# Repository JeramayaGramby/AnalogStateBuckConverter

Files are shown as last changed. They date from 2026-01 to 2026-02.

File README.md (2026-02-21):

# Multi-Range Analog State Buck Converter

A deliberately over-engineered, pedagogically motivated power-electronics platform that demonstrates how classical analog circuitry can implement deterministic state behavior — without a microcontroller, firmware, or digital logic.

---

## Table of Contents

- [Multi-Range Analog State Buck Converter](#multi-range-analog-state-buck-converter)
  - [Table of Contents](#table-of-contents)
  - [Overview](#overview)
  - [Functional Description](#functional-description)
    - [State Table](#state-table)
    - [Enable Logic](#enable-logic)
  - [Design Philosophy \& Constraints](#design-philosophy--constraints)
    - [1. All Components Must Be Sourced From American Manufacturers](#1-all-components-must-be-sourced-from-american-manufacturers)
    - [2. Every Component Must Have a Complete Digital Asset Package](#2-every-component-must-have-a-complete-digital-asset-package)
    - [3. No Obsolete, End-of-Life, or Newly Released Components](#3-no-obsolete-end-of-life-or-newly-released-components)
  - [Use Case \& Motivation](#use-case--motivation)
  - [Challenges](#challenges)
  - [Potential Improvements](#potential-improvements)
  - [Repository Structure](#repository-structure)
  - [Educational \& Professional Value](#educational--professional-value)

---

## Overview

The **Multi-Range Analog State Machine Buck Converter** accepts a wide, potentially unstable input voltage (5 V – 24 V) and autonomously selects one of three independent buck converter stages based on the instantaneous input voltage. Each stage is optimized for a specific voltage window, ensuring predictable, safe, and efficient **5 V regulation** even in environments where electrical infrastructure is unreliable or inconsistent.

At its core, the system is an **analog state machine** built from comparators, open-collector logic, a dual NPN transistor, and a P-channel MOSFET high-side switch. State transitions are governed entirely by analog voltage thresholds and hysteresis — no firmware, no lookup tables, no digital logic.

| Parameter | Value |
|---|---|
| Input Voltage Range | 5 V – 24 V |
| Output Voltage | 5 V (regulated) |
| Recommended Output Current | 2 A |
| Absolute Max Output Current | 3 A |
| Active Buck Stages | 3 (mutually exclusive) |
| Control Architecture | Analog state machine |

---

## Functional Description

The system operates in four mutually exclusive states, each defined by the instantaneous input voltage $V_{IN}$.

### State Table

| $V_{IN}$ Range | Active State | Behavior |
|---|---|---|
| < 5 V | State 0 | System disabled; no buck converter enabled |
| 5 V – 9.25 V | State 1 | Buck 1 enabled |
| 9.25 V – 12.25 V | State 2 | Buck 2 enabled |
| > 12.25 V | State 3 | Buck 3 enabled |

### Enable Logic

Three comparators generate threshold signals $F_1$, $F_2$, $F_3$, which are combined into per-stage enable signals:

$$EN_1 = F_1 \cdot \overline{F_2}$$

$$EN_2 = F_2 \cdot \overline{F_3}$$

$$EN_3 = F_3$$

This guarantees that **only one buck converter can ever be active at a time**, eliminating overlap, shoot-through, and undefined states. The Boolean logic is implemented using open-collector outputs and a dual NPN transistor pair — producing clean, debuggable, and observable behavior without relying on any digital ICs.

---

## Design Philosophy & Constraints

This project was built under a strict set of real-world constraints to simulate the pressures of professional hardware development and supply-chain engineering.

### 1. All Components Must Be Sourced From American Manufacturers

In response to the tariff volatility and supply-chain instability of 2025, every component — down to each resistor and capacitor — must be manufactured in the United States. This constraint forces:

- Working within a limited vendor ecosystem
- Understanding the geopolitical and regulatory implications of component sourcing
- Building a design resilient to international supply disruptions

It also ensures that all components share the same manufacturing standards, tolerances, and compliance frameworks.

### 2. Every Component Must Have a Complete Digital Asset Package

To eliminate common PCB design bottlenecks, every part must include:

- A verified schematic symbol
- A verified PCB footprint
- A manufacturer-provided 3D model
- A complete datasheet

This rule was established after the very first component selected for the project had no symbol, no footprint, and no 3D model. After wrestling with mismatched footprints and incomplete documentation, the policy became absolute: **no part enters the design unless it is fully documented and fully modeled.**

This dramatically reduces layout errors, accelerates ECO cycles, and ensures the final 3D assembly is accurate enough for enclosure design, thermal modeling, and manufacturing review.

### 3. No Obsolete, End-of-Life, or Newly Released Components

Only parts with:

- At least **1,000 units in stock** at the time of selection
- **Stable production status**
- **Mature documentation**

This avoids designing around parts that may disappear, change spec, or lack real-world validation.

---

## Use Case & Motivation

The device is designed for environments where electrical infrastructure is **inconsistent, under-regulated, or prone to voltage fluctuations** — conditions common in many developing regions. While handheld device chargers in first-world countries typically include robust overvoltage and overcurrent protection, this is not universally true.

By supporting a 5–24 V input range and regulating to a stable 5 V output, the system provides a safe, predictable power source for:

- Mobile devices
- Portable electronics
- Embedded systems
- Field equipment

The analog state machine ensures the correct buck converter is always selected for the input voltage, protecting downstream devices from unstable or dangerous power conditions.

---

## Challenges

> As this is one of my first PCB designs, there were no shortages of challenges.
> The first lesson I learned in PCB design pertaining to the numerous revisions is that every year, at the end of January, automotive manufacturers will order any and every automotive rated peripheral, whether it is AEC-5000 rated, AEC-1200 rated, or barely CE certified.
> Around 41% of this PCB's components are Automotive rated, and this means that the Bill of Materials needed several revisions to ensure the design continued to meet sourceability constraints. Irreplaceable components are noted in the Bill of Materials along with potential drop in replacements. 
> There are several components that currently do not meet the sourcability requirements, even before the end of January. This includes the final diode, the NPN transistor and the P channel MOSFET. The voltage requirements for these components limit the number of drop-in replacement options.   
---

## Potential Improvements

> *This section is reserved for proposed enhancements, alternative architectures, and future revision ideas.*

---

## Repository Structure

```
AnalogStateBuckConverter/
├── altium_footprints/      # Altium schematic symbols and PCB footprints (by block)
├── cad/
│   ├── project_files/      # KiCad schematic and PCB project files
│   └── step/               # 3D STEP models (by block)
├── docs/
│   ├── BOM/                # Bill of materials
│   ├── datasheets/         # Component datasheets (by block)
│   ├── symbols/            # Schematic symbol assets (by block)
│   └── History/            # Design revision history
└── footprints/             # KiCad footprint files (by block)
```

---

## Educational & Professional Value

This project is intentionally over-engineered — and that is its strength. It serves as a comprehensive learning platform merging:

| Domain | Topics Covered |
|---|---|
| Analog Circuit Design | Comparators, hysteresis, open-collector logic, MOSFET switching |
| Power Electronics | Buck converter topology, efficiency, thermal considerations |
| State Machine Theory | Analog implementation of deterministic finite automata |
| Supply-Chain Engineering | Domestic sourcing, lifecycle management, BOM discipline |
| CAD & Documentation | Symbol creation, footprint verification, 3D modeling, datasheet review |

**For academic reviewers** — demonstrates mathematical maturity, systems thinking, and a willingness to explore non-digital control architectures.

**For recruiters** — demonstrates real-world engineering discipline, supply-chain awareness, and the ability to build production-ready hardware from first principles.

---

*Designed and documented by [JeramayaGramby](https://github.com/JeramayaGramby)*

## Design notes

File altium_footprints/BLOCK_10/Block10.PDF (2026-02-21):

Change Order Report For Project | DC3.PrjPcb And DC3.PrjPcb
Action Object | Change Document | Status

Add Components
Add | C_BULK_5V | To DC3.PcbDoc
Add | C_HF_5V | To DC3.PcbDoc
Add | C_MF_5V | To DC3.PcbDoc
Add | D_TVS_5V | To DC3.PcbDoc
Add | USBC | To DC3.PcbDoc

Add Nets
Add | 5V_OUT | To DC3.PcbDoc
Add | GND | To DC3.PcbDoc

Add Component Classes
Add | Block10 | To DC3.PcbDoc

Add Rules
Add | Supply Nets [Voltage = 0.000] | To DC3.PcbDoc
InNet('5V_OUT')
Add | Supply Nets [Voltage = 0.000] | To DC3.PcbDoc
InNet('GND')
Saturday 7-Feb-07/2026 7:04:06 PM | Page 1 of 1

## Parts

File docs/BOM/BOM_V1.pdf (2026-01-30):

## Block 1 — Input protection, rectification, and 5 V linear

Ref | Part Number | Description | Qty
J1 | PJ-063AH | DC barrel jack, through-hole, center-positive | 1
F1 | OPTF0078P | Fuseholder | 1
F2 | 0239003.MXP | 3 A fuse, time-delay (use 0239003.HXP footprint) | 1
D1 | SBR3U60P1 | 3 A, 60 V SBR rectifier | 1
C1 | EDK476MD5DS9HAA | 47 µF electrolytic capacitor | 1
C2 | C1210C106K5PACTU | 10 µF, 1210, X5R ceramic capacitor | 1
M1 | LM340MPX-5.0/NOPB | 5 V linear regulator (LM7805-type) | 1
C3 | C0603C104K5RACTU | 0.1 µF, 0603, X7R ceramic capacitor | 1
C4 | C0603C104K5RACTU | 0.1 µF, 0603, X7R ceramic capacitor | 1
D2 | TL431BQDBZR | Precision shunt regulator | 1

## Block 2 — VIN sense, comparator/EN/F2 logic network

Ref | Part Number | Description | Qty
C5 | C1210C226M5PACTU | 22 µF, 1210, X5R, 50 V ceramic capacitor | 1
R1 | CRCW060310K0FKEA | 10 kΩ, 0603, 1% resistor (primary shunt sense) | 1
R2 | CRCW060310K0FKEA | 10 kΩ, 0603, 1% resistor | 1
R3 | CRCW060310K0FKEA | 10 kΩ, 0603, 1% resistor | 1
R5 | CRCW060310K0FKEA | 10 kΩ, 0603, 1% resistor | 1
R7 | CRCW060310K0FKEA | 10 kΩ, 0603, 1% resistor | 1
R1_EN1 | CRCW060310K0FKEA | 10 kΩ, 0603, 1% resistor (EN logic) | 1
R1_EN2 | CRCW060310K0FKEA | 10 kΩ, 0603, 1% resistor (EN logic) | 1
R1_EN3 | CRCW060310K0FKEA | 10 kΩ, 0603, 1% resistor (EN logic) | 1
R1_F2 | CRCW060310K0FKEA | 10 kΩ, 0603, 1% resistor (F2 logic) | 1
R2_F2 | CRCW060310K0FKEA | 10 kΩ, 0603, 1% resistor (F2 logic) | 1
R4 | CRCW060327K4FKEA | 27.4 kΩ, 0603, 1% resistor | 1
R6 | CRCW060339K2FKEA | 39.2 kΩ, 0603, 1% resistor | 1

## Block 3 — Logic switching, comparator, P-FET branch

Ref | Part Number | Description | Qty
C1_L1 | C1210C226M8PACTU | 22 µF, 1210, X6S, 63 V ceramic capacitor | 1

# Actual BOM FINAL

Friday, January 30, 2026 3:51 PM

New Section 14 Page 1

C2_L1 | C1210C226M8PACTU | 22 µF, 1210, X6S, 63 V ceramic capacitor | 1
L1 | LM339BIRTER | Quad comparator, open-collector outputs | 1
T1 | FMB3904 | NPN transistor, SOT-23 | 1
R7 | CRCW0603100KFKEA | 100 kΩ, 0603, 1% resistor (VIN_FUSED branch to P-FET source) | 1
M2 | SI2333CDS-T1-GE3 | P-channel MOSFET, logic-level, SOT-23 | 1

## Block 4 — Buck1 (TPS543321) + peripherals (updated R9)

Ref | Part Number | Description | Qty
C6 | C1210C226M5PACTU | 22 µF, 1210, X5R, 50 V ceramic capacitor (input bulk) | 1
C7 | C0603C104K5RACTU | 0.1 µF, 0603, X5R, 50 V ceramic capacitor (input bypass) | 1
U1 | TPS543321RQFR | 3 A synchronous buck regulator | 1
L1 | IHLP2525CZER2R2M01 | 2.2 µH shielded inductor, 2525 footprint | 1
R8 | TNPV1206330KBYEA | 330 kΩ, 1206, 0.1% resistor (MODE pin configuration) | 1
Boot_C1 | C0402C223K5RACTU | 22 nF, 0402, X7R, 50 V ceramic capacitor (bootstrap) | 1
R9 | CRCW040256K2FKED | 56.2 kΩ, 0402, 1% resistor (feedback top, raised to ~5.3 V) | 1
R10 | CRCW060310K0FKEA | 10 kΩ, 0603, 1% resistor (feedback bottom) | 1
C8 | C1210C226M5PACTU | 22 µF, 1210, X5R, 50 V ceramic capacitor (output bulk) | 1
C9 | C0603C104K5RACTU | 0.1 µF, 0603, X5R, 50 V ceramic capacitor (output bypass) | 1

## Block 5 — Buck2 (TPS563300) + peripherals (updated R10)

Ref | Part Number | Description | Qty
C10 | C1210C226M5PACTU | 22 µF, 1210, X5R, 50 V ceramic capacitor (input bulk) | 1
C11 | C0603C104K5RACTU | 0.1 µF, 0603, X5R, 50 V ceramic capacitor (input bypass) | 1
U2 | TPS563300DRLR | 3 A synchronous buck regulator | 1
L2 | IHLP2525CZER2R2M01 | 2.2 µH shielded inductor, 2525 footprint | 1
Boot_C2 | C0402C223K5RACTU | 22 nF, 0402, X7R, 50 V ceramic capacitor (bootstrap) | 1
R10 | CRCW040256K2FKED | 56.2 kΩ, 0402, 1% resistor (feedback top, raised to ~5.3 V) | 1
R11 | CRCW060310K0FKEA | 10 kΩ, 0603, 1% resistor (feedback bottom) | 1
C12 | C1210C226M5PACTU | 22 µF, 1210, X5R, 50 V ceramic capacitor (output bulk) | 1
C13 | C0603C104K5RACTU | 0.1 µF, 0603, X5R, 50 V ceramic capacitor (output bypass) | 1

## Block 6 — Buck3 (LT8609A) + peripherals (updated R12/R13)

Ref | Part Number | Description | Qty
C10 | C1210C226M5PACTU | 22 µF, 1210, X5R, 50 V ceramic capacitor (input bulk) | 1

New Section 14 Page 2

C11 | C0603C104K5RACTU | 0.1 µF, 0603, X5R, 50 V ceramic capacitor (input bypass) | 1
U3 | LT8609AEDDM#TRPBF | 3 A, 2 MHz synchronous buck regulator | 1
C12 | C0805C105J5RACTU | 1 µF, 0805, C0G, 50 V ceramic capacitor (INTVcc decoupling) | 1
R11 | CRCW060318K2FKEA | 18.2 kΩ, 0603, 1% resistor | 1
Boot_C3 | C0603C104K5RACTU | 0.1 µF, 0603, X5R, 50 V ceramic capacitor (bootstrap) | 1
L2 | IHLP2525CZER2R2M01 | 2.2 µH shielded inductor, 2525 footprint | 1
R12 | CRCW0603845KFKEA | 845 kΩ, 0603, 1% resistor (feedback top, targets ~5.36 V) | 1
R13 | CRCW0603187KFKEA | 187 kΩ, 0603, 1% resistor (feedback bottom) | 1
C13 | 600S100JT250XT | 10 pF, 250 V RF ceramic capacitor (compensation) | 1
C14 | C1210C226M5PACTU | 22 µF, 1210, X5R, 50 V ceramic capacitor (output bulk) | 1
C15 | C0603C104K5RACTU | 0.1 µF, 0603, X5R, 50 V ceramic capacitor (output bypass) | 1

## Block 7 — TPS_1 (Buck1 5V_OUT protection)

Ref | Part Number | Description | Qty
TPS_1 | TPS1H200AQDGNRQ1 | Smart high-side switch, 40 V, 200 mΩ | 1
R_CL_1 | CRCW06031K20FKEA | 1.2 kΩ, 0603, 1% resistor (current-limit configuration) | 1
C_DEL_1 | VJ0805Y681KXACW1BC | 680 pF, 0805, Y5V ceramic capacitor (delay/timing) | 1
C16 | VJ0603Y105KXACW1BC | 1 µF, 0603, Y5V ceramic capacitor (decoupling) | 1
C17 | VJ0603Y104KXXAC | 0.1 µF, 0603, X7R ceramic capacitor (bypass/filter) | 1

## Block 8 — TPS_2 (Buck2 5V_OUT protection)

Ref | Part Number | Description | Qty
TPS_2 | TPS1H200AQDGNRQ1 | Smart high-side switch, 40 V, 200 mΩ | 1
R_CL_2 | CRCW06031K20FKEA | 1.2 kΩ, 0603, 1% resistor (current-limit configuration) | 1
C_DEL_2 | VJ0805Y681KXACW1BC | 680 pF, 0805, Y5V ceramic capacitor (delay/timing) | 1
C18 | VJ0603Y105KXACW1BC | 1 µF, 0603, Y5V ceramic capacitor (decoupling) | 1
C19 | VJ0603Y104KXXAC | 0.1 µF, 0603, X7R ceramic capacitor (bypass/filter) | 1

## Block 9 — TPS_3 (Buck3 5V_OUT protection)

Ref | Part Number | Description | Qty
TPS_3 | TPS1H200AQDGNRQ1 | Smart high-side switch, 40 V, 200 mΩ | 1
R_CL_3 | CRCW06031K20FKEA | 1.2 kΩ, 0603, 1% resistor (current-limit configuration) | 1
C_DEL_3 | VJ0805Y681KXACW1BC | 680 pF, 0805, Y5V ceramic capacitor (delay/timing) | 1
C20 | VJ0603Y105KXACW1BC | 1 µF, 0603, Y5V ceramic capacitor (decoupling) | 1

New Section 14 Page 3

C21 | VJ0603Y104KXXAC | 0.1 µF, 0603, X7R ceramic capacitor (bypass/filter) | 1

## Block 10 — Shared 5V_OUT node

Ref | Part Number | Description | Qty
C_BULK_ 5V | T54EE476M050ESA1 00 | 47 µF, 50 V polymer tantalum capacitor, 2917 (bulk output cap) | 1
C_MF_5V | VJ0603Y105KXACW1 BC | 1.0 µF, 16 V, X7R, 0603 ceramic capacitor (connector-side, mid-freq) | 1
C_HF_5V | VJ0603Y104KXXAC | 0.1 µF, 25 V, X7R, 0603 ceramic capacitor (connector-side, high-freq) | 1
D_TVS_5V | SMF5.0A | 5 V TVS diode, SOD-123FL | 1
J_USB_C | USB4125-GF-A | USB-C receptacle, mid-mount | 1

## Block 11 — External adapter plug + recommended 1 m cables

Ref | Part Number | Description | Qty
P_ADAPT | 70235K607 | Barrel plug for 12 V, 2 A adapter (mates with PJ-063AH) | 1
C_USBCC_1M | CAB004BT1MW H | Belkin 1 m USB-C to USB-C cable, 60 W-class, 3 A-rated power conductors | 1
C_USBA_C_ 1M | F2CU029BT1M- BLK | Belkin 1 m USB-A to USB-C cable, up to 3 A charging | 1
C_USBA_L_ 1M | CAA001BT1MW H | Belkin 1 m USB-A to Lightning cable, MFi-class for iPhone/iPad | 1

New Section 14 Page 4

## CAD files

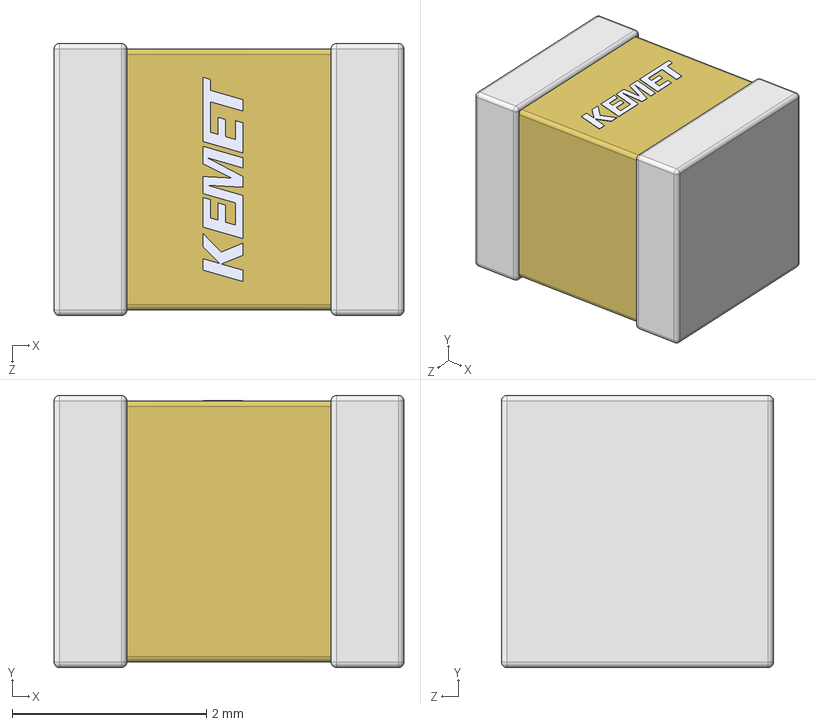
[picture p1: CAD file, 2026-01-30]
cad/step/BLOCK_1/C1210C106K5PAC7800.step
3.60 x 2.80 x 2.80 mm

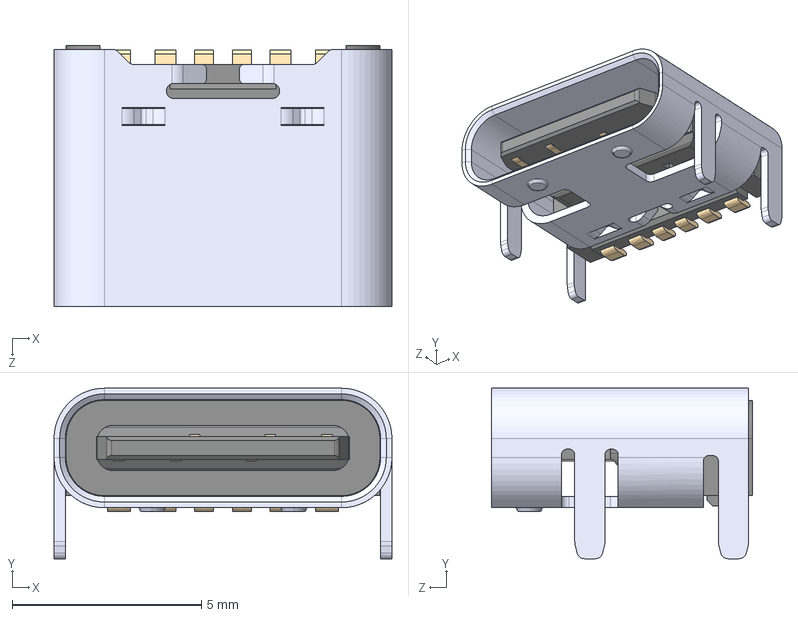
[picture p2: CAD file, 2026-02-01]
cad/step/BLOCK_10/USB4125-GF-A_REVA2.step
8.94 x 4.51 x 6.90 mm

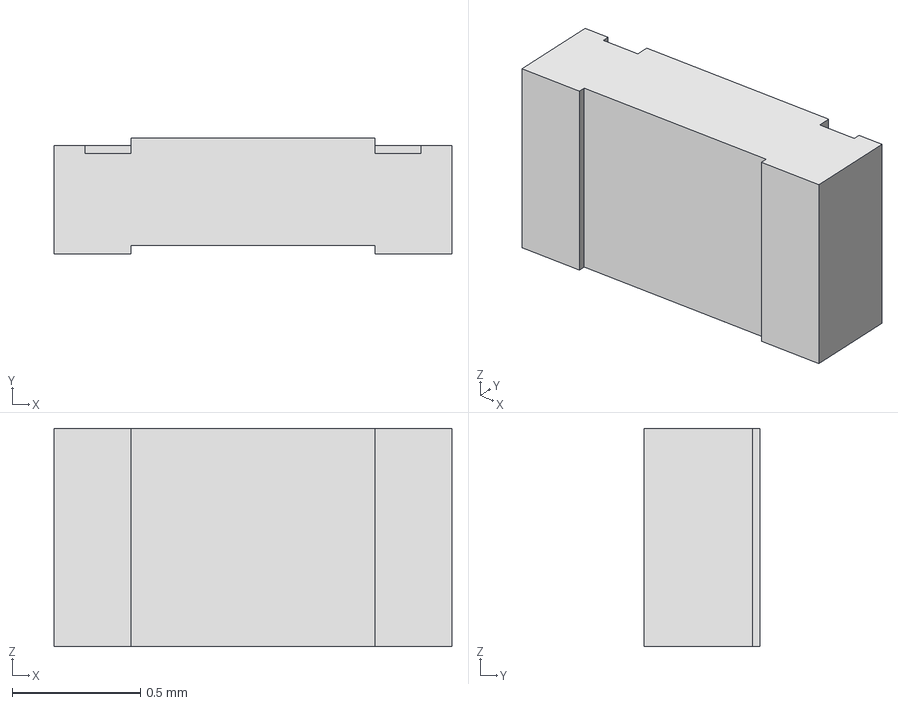
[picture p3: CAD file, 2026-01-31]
cad/step/BLOCK_2/CRCW060339K2FKEA.stp
1.55 x 0.45 x 0.85 mm

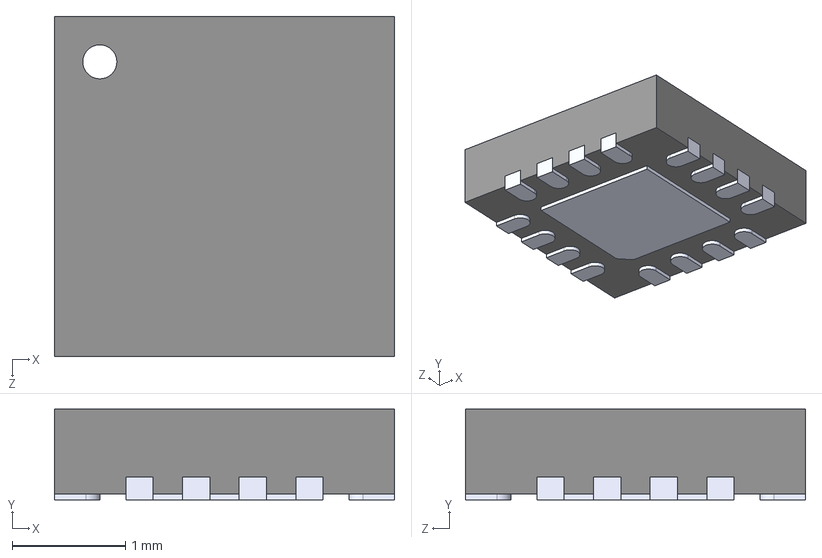
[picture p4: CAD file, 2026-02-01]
cad/step/BLOCK_3/LM339BIRTER.STEP
3.00 x 0.8 x 3.00 mm

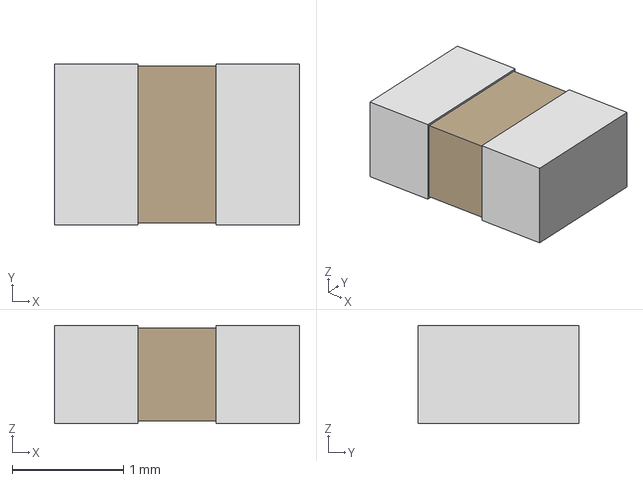
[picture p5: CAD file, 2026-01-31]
cad/step/BLOCK_6/C0805C104K5RACTU.step
2.20 x 1.45 x 0.88 mm

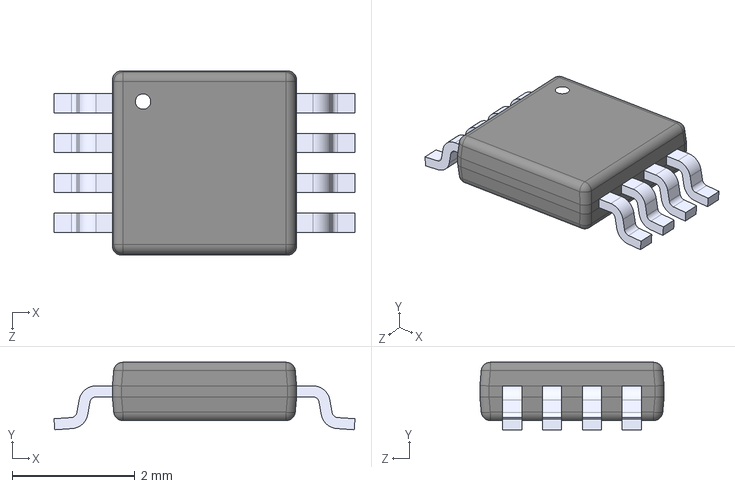
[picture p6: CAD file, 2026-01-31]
cad/step/BLOCK_7/TPS1H200AQDGNRQ1.step
4.90 x 1.10 x 3.00 mm

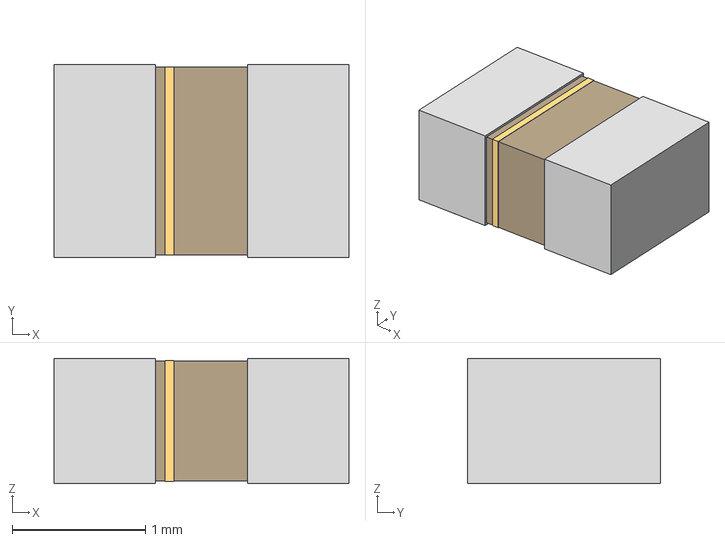
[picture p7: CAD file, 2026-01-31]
cad/step/BLOCK_9/KGM21NR71H681KT.step
2.21 x 1.45 x 0.94 mm

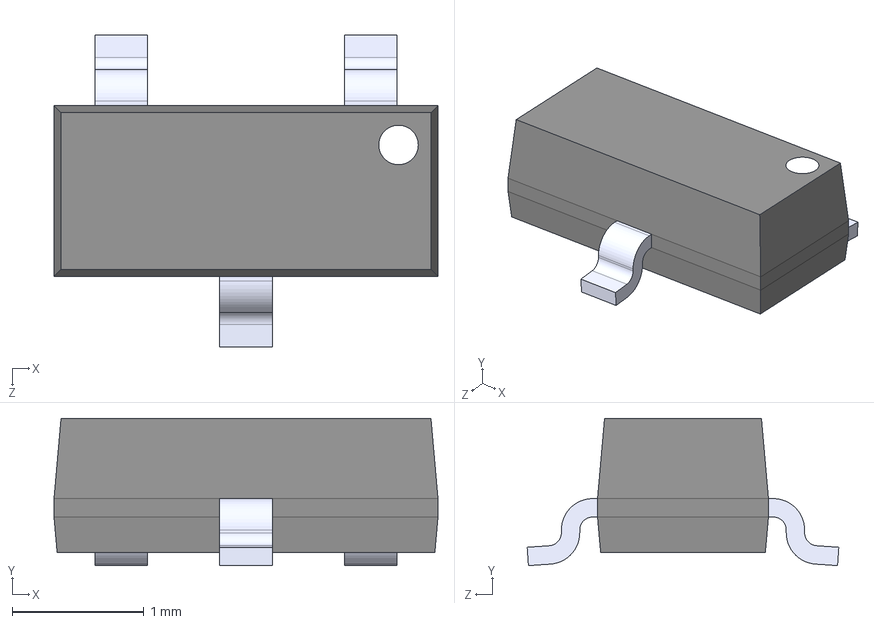
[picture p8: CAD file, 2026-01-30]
cad/step/BLOCK_1/TL431BQDBZR.step
2.92 x 1.12 x 2.37 mm

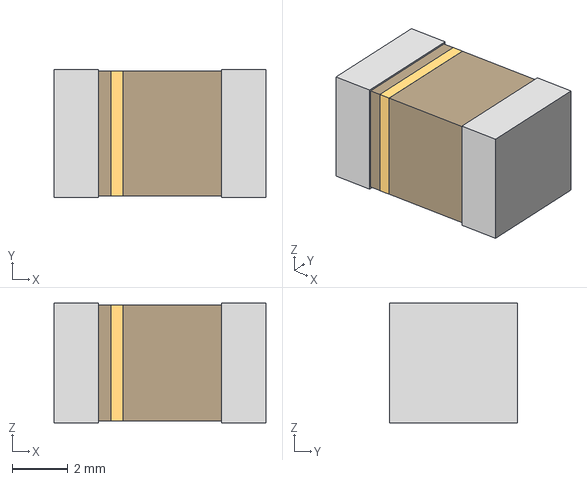
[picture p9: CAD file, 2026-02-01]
cad/step/BLOCK_10/T59EE476M050C0100.step
7.59 x 4.60 x 4.29 mm

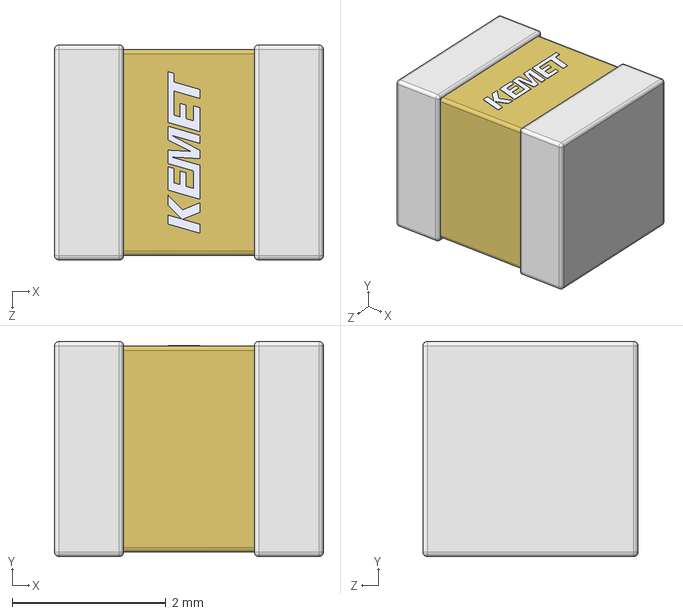
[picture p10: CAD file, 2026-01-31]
cad/step/BLOCK_3/C1210C226M8PACTU.step
3.50 x 2.80 x 2.80 mm

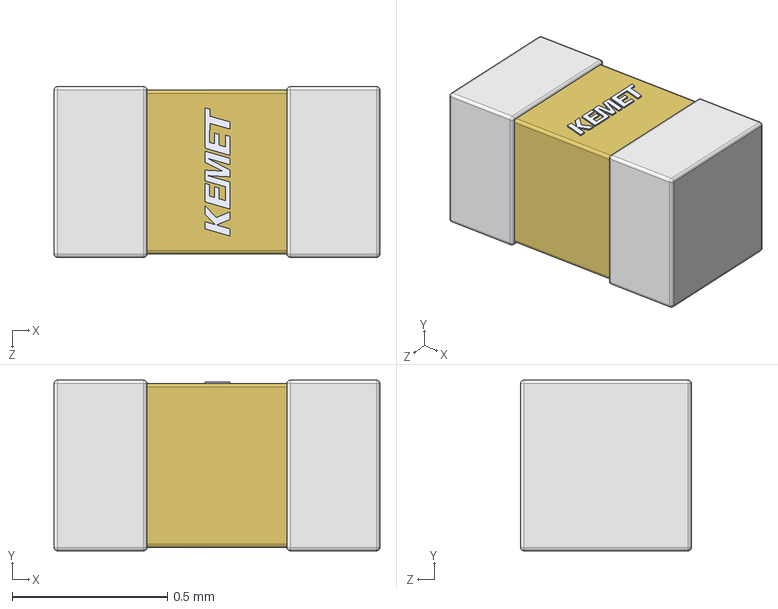
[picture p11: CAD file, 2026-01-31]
cad/step/BLOCK_4/C0402C223K5RACTU.step
1.05 x 0.55 x 0.55 mm

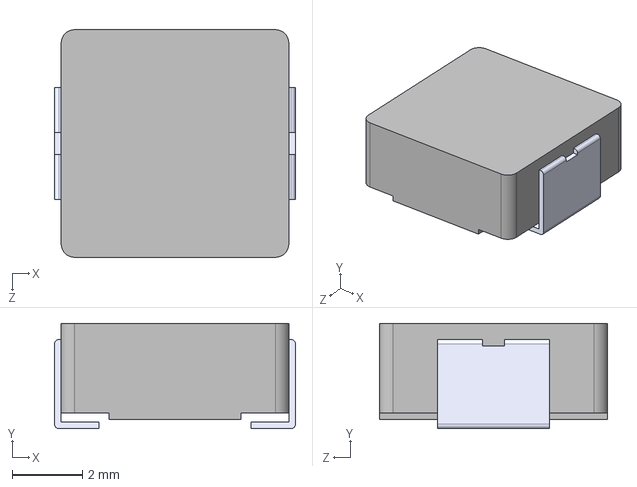
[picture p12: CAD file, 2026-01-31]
cad/step/BLOCK_5/IHLP2525CZER2R2M01.step
6.86 x 3.00 x 6.48 mm

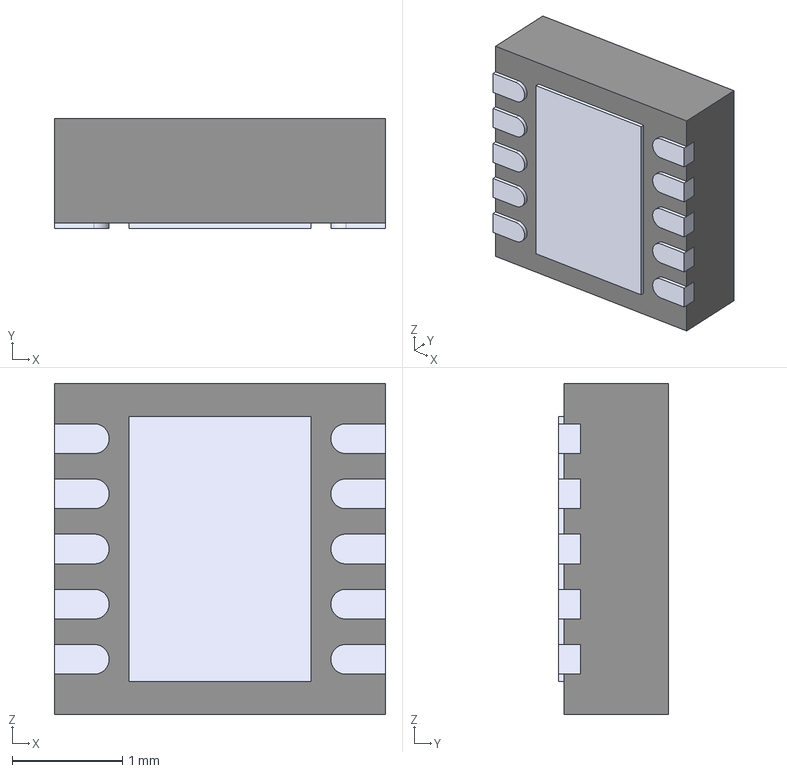
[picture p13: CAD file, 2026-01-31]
cad/step/BLOCK_6/LT8609AEDDM#TRPBF.STEP
3.00 x 1.00 x 3.00 mm
Body_Solid1
Body002_Solid1
Array002_Solid1 x 5
Array003_Solid2 x 4
Body003_Solid1
Body004_Solid1

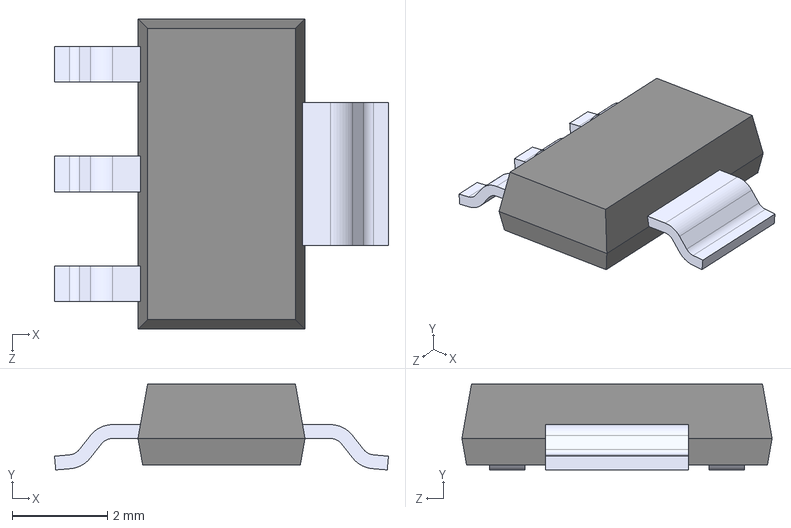
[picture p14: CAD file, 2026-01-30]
cad/step/BLOCK_1/LM340MPX-5.0_NOPB.step
7.00 x 1.80 x 6.50 mm

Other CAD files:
cad/step/BLOCK_1/EDK476M050S9HAA.step
cad/step/BLOCK_1/FUSE_0239003_MXP_LTF.step
cad/step/BLOCK_1/FUSE_0PTF0078P_LTF.step
cad/step/BLOCK_1/SBR3U60P1Q-13.stp
cad/step/BLOCK_1/Same_Sky_PJ-063AH.step
cad/step/BLOCK_10/C0603C104K5RAC7867.step
cad/step/BLOCK_10/SMF5_0A.step
cad/step/BLOCK_10/VJ0603Y105KXJCW1BC.step
cad/step/BLOCK_3/NPNTRANSISTOR.step
cad/step/BLOCK_3/PCHANNEL.step
cad/step/BLOCK_4/CRCW060310K0FKEA.step
cad/step/BLOCK_4/TNPV1206330KBYEA.step
cad/step/BLOCK_4/TPS543321RQFR.stp
cad/step/BLOCK_5/A768EB226M1HLAE048.step
cad/step/BLOCK_5/CRCW040256K2FKED.STEP
cad/step/BLOCK_5/TPS563300DRLR.stp
cad/step/BLOCK_6/600S100JT250XT4K.step
cad/step/BLOCK_6/A768EB226M1HLAE048.step
cad/step/BLOCK_6/CRCW0603187KFKEA.step
cad/step/BLOCK_6/CRCW060318K2FKEA.step
cad/step/BLOCK_6/CRCW0603845KFKEA.step
cad/step/BLOCK_7/CRCW06031K20FKEA.step
cad/step/BLOCK_8/CRCW06031K20FKEA.step
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

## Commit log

2026-01-30 Include footprints, BOM_V1 supporting documents, and first four components of Block 1. Change file structure to maintain Block sectionality.
    [BOM_V1.xlsx, FUSE_0239003_MXP_LTF.step, FUSE_0PTF0078P_LTF.step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]
2026-01-30 Include first rectifier diode. Make minor change to first block to remove a non-US sourced part.
    [BOM_V1.xlsx, EDK476M050S9HAA.step]
2026-01-30 Fix syntax issue in BOM.
    [BOM_V1.xlsx]
2026-01-30 Finalize Block 1 components.
    [C0603C104K5RAC7867.step, C1210C106K5PAC7800.step, LM340MPX-5.0_NOPB.step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]
2026-01-31 Finalize Block 1 and 2 components.
    [A768EB226M1HLAE048.step, CRCW060310K0FKEA.step, CRCW060339K2FKEA.stp]
2026-01-31 Include footprints, datasheets, symbols and step files for Block 2 and 3.
    [A768EB226M1HLAE048.step, C1210C226M8PACTU.step, CRCW0603100KFKEA.step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]
2026-01-31 Include footprints, datasheets, symbols and step files for Block 4 and 5.
    [A768EB226M1HLAE048.step, C0603C104K5RAC7867.step, CCS_CCSTD_0402_L1.05W0.55T0.55B0.3.step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]
2026-01-31 Include footprints, datasheets, symbols and step files for Block 6, 7, 8 and 9. Include buck2 components for block 5.
    [600S100JT250XT4K.step, A768EB226M1HLAE048.step, C0603C104K5RAC7867.step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]
2026-02-01 Include footprints, datasheets, symbols and step files for Block 10. Rectify missing and mislabeled files in block 3 and 4.
    [A768EB226M1HLAE048.step, C0402C223K5RACTU.step, C0603C104K5RAC7867.step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]
2026-02-07 Add Altium folder and corresponding files per block.
    [AltiumLibs.SchLib, C0603C104K5RACTU.PcbLib, C0603C104K5RACTU.SchLib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]
2026-02-21 Include Altium directories and first draft of project README.
    [CRCW06031K20FKEA.PcbLib, CRCW06031K20FKEA.SchLib, DC3.PcbDoc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]
